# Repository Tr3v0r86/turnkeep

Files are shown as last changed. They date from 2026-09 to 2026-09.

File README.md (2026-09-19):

# Turnkeep

**Bring the game back to the table.** A printable case for dice, a miniature and a pen, with an offline character display powered by the non-touch LilyGo T-Display-S3.

Real dice, paper notes and an offline device for the pieces that matter. **Make it. Modify it. Copy it. Reinvent it. Make it yours.**

[Explore the website](https://tr3v0r86.github.io/turnkeep/) · [Hardware and assembly](hardware/) · [Firmware and character packs](firmware/)

## Build this prototype

The first public release combines the **v0.2 body and L-shaped rolling lid** with the **v0.3 adjustable screen module**. Keep the screen-module parts together. The bare shell is nominally 166 × 110 × 36 mm; final wrapped dimensions and mass have not been measured.

- `hardware/`: original editable CAD, printable exports, wrap patterns, BOM and assembly instructions.
- `firmware/`: standalone ESP-IDF project, host simulator and validated compile-time JSON character tooling. The included character is synthetic.
- `site/`: the complete static website, self-hosted fonts and images.
- `tools/`: deterministic release packaging and checksums, using Python's standard library.

Read the hardware guide before buying parts. Print fit checks first. Fit and finish depend on your printer, inserts and covering material. Choose and verify your own compatible battery and connector polarity.

## What works, what remains

The prototype interface supports two-button navigation, health edits, actions, spells, resources and offline state. Initial sleep and wake checks passed on the prototype. Personal JSON packs validate and compile into firmware; phone-based setup is not implemented.

[Try the phone-setup prototype](https://tr3v0r86.github.io/turnkeep/setup.html): scan a QR, preview Beyond/photo import, review a synthetic character and simulate a transfer. No actual OCR, Beyond integration or device pairing is implemented. CYD, colour e-paper and round-display [CAD concepts](hardware/concepts/) are unvalidated envelope studies, separate from the current printable design.

The v0.3 mechanical fit still needs physical acceptance. Battery runtime, standby current, thermal behavior, repeated recovery cycles and a complete tabletop session are not yet validated. This is an experimental maker release, not a finished consumer product. No ready-to-flash binary is advertised.

## Build the website and download package

```sh
python3 tools/release.py
python3 -m http.server 8197 --directory site
```

Open http://localhost:8197. `RELEASE_FILES.txt` is the explicit publication allowlist. The generated ZIP and manifest go into `site/downloads/`; the manifest records sizes, SHA-256 hashes and the source revision. GitHub Pages runs the same script. See [deployment](docs/deployment.md).

## License and contributions

Original hardware: CERN-OHL-P-2.0. Original firmware and website: MIT. Original docs and images: CC BY 4.0. [Full licensing map](LICENSE.md).

Issues and pull requests are welcome. Include the component revision, board version, printer/material or toolchain, exact reproduction steps and photographs or logs where helpful. Do not upload game-book extracts, other people's character art, device dumps, secrets or unlicensed models. Public releases of Turnkeep are maintained here; unrelated prototype projects are not automatically synchronized.

The files, firmware and guides stay free forever. Fully assembled boxes from Trevor are coming soon. [Buy Trevor a coffee](https://buymeacoffee.com/padlano) is optional support, not a preorder.

[Development roadmap](docs/roadmap.md): character import → CYD → phone companion → made-to-order builds → colour e-paper → round display.

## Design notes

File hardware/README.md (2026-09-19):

# Turnkeep hardware

A compact 166 × 110 × 36 mm bare case with a fixed screen corner and removable L-shaped lid. Flip the lid 180° and magnetically dock it to the front edge to make a rolling tray. Both halves rest on the table; the dock is not a carrying handle. Current geometry combines the retained v0.2 body/lid with the v0.3 faceplate and adjustable board support. This remains a prototype pending physical acceptance.

## Print and assemble

Print one each of `stl/01_body.stl` and `stl/02_rolling_lid.stl`, then `REPAIR_PRINT_PLATE.stl` once (eight electronics-module parts). Alternatively print the four module STL designs in the quantities encoded in their filenames. Units: millimetres, 100% scale. Body/lid: 0.4 mm nozzle, 0.20 mm layers, four walls, five top/bottom layers and 15–20% infill as an unverified starting profile. Inspect support preview around the horizontal docking holes. Module: 0.16 mm layers, four walls, 25% infill, no supports. Parts fit a 180 mm build envelope.

Print `08_fit_coupon` first to test insert/magnet fit, `09`/`10` to test lid clearance and `11`/`12` to test docking. Coupon rows at y=12/33/52 test 2.9–3.2 mm insert pilots, 6.1–6.4 mm large magnet pockets and 3.1–3.4 mm small magnet pockets, increasing left to right. Final pilot/pocket diameters are 3.0/6.3/3.3 mm. Test a module button/support before a full print; do not force tight fits.

Follow [the module assembly guide](ASSEMBLY.md), including first-contact-only support adjustment. Never use the screws to flatten a rocking board. Fit hardware and verify button return, display seating, reset and USB access before applying coverings. The front frame supports the display; the glass is not a clamp surface.

| Full-build item | Quantity / specification |
|---|---|
| Board | 1 LILYGO T-Display-S3, bare headers; verify your revision |
| Battery envelope | Up to 57 × 39 × 8 mm; compatible protected cell, connector/polarity verified against your board |
| Heat-set inserts | 12 M2, 4 mm long, 3.2 mm OD: four body, four faceplate, four adjusters |
| M2 × 8 mm screws | 8: four case screws, four adjusters |
| M2 × 10 mm screws | 4 carrier mounts |
| 6 × 2 mm magnets | 10: four closure, six docking |
| 3 × 2 mm magnets | 6 closure |
| Coverings | Nominal 2 mm felt floors; optional 1 mm PVC outside |
| Consumables | Suitable magnet/cover adhesive, thin soft battery mounting pad |

Dry-fit and mark all magnet polarities before gluing. Keep magnet faces, collars, sockets and lid mating edges clear of felt/PVC/glue. Route the battery wire clear of bosses and screw tips; its connector and bend path are not fully modelled. Do not clamp or puncture the cell. Seven dice pockets and a 155 × 16 mm pen pocket are nominal envelopes; test your contents. The small accessory pocket is generic and includes no miniature model.

## Source and reproduction

Use Python 3.14 (tested on macOS arm64). Create a virtual environment and install `requirements.txt`; `requirements-lock.txt` records the complete tested environment.

```sh
python -m venv .venv
. .venv/bin/activate
pip install -r requirements.txt
python build.py
python package.py
python upholstery/make_patterns.py
python upholstery/make_felt.py
python render.py
python verify.py
```

Run from `hardware/`. `case.py` defines the retained body/lid parametrically; `build.py` defines the current module and generates eleven printable designs (including five fit coupons), original-parts-only `case-assembly.step`, preview meshes and `validation.json`. STEP is editable boundary-representation geometry; Python is the parameter source. `package.py` produces the eight-piece print plate and a portable hardware map. `render.py` renders the actual case meshes to `../media/hero.png` without external fonts or private assets. No historical source mutation scripts are required. VTK rendering needs a graphics-capable session; on headless Linux provide a compatible EGL/OSMesa or Xvfb setup.

For nominal board/contact checks, acquire the manufacturer's model independently and run `python build.py --board-step /path/to/t-display-s3-full.stp`. It is never added to exported STEP or preview meshes. The default build explicitly records board checks as skipped; see [provenance](PROVENANCE.md).

## Coverings and verification

`upholstery/felt-pocket-templates.svg` and `make_felt.py` supply editable floor and lid felt templates with magnet/docking trim guides; verify the 100 mm line.

[Two-piece upholstery](upholstery/README.md) provides the editable generator and two actual-size A4 landscape PDF pages. Paper-test first, then test a scrap of the actual 1 mm material. Keep the current screen surround painted and removable. The shape check establishes exactly two connected nets; it does not prove physical PVC fit.

Build assertions check connected valid solids, watertight meshes, dimensions, non-overlap, insertion/adjustment sweeps, screw/battery clearances and open/closed lid geometry. Optional board checks cover clearances and contact areas. Physical printer tolerances, actual board revision, magnetic holding force, button loads, cable fit, upholstery and long-term creep remain unverified. This package does not claim a completed physical fit or slice validation.

AliExpress specification-search links for every material and common tools are in the [website materials list](https://tr3v0r86.github.io/turnkeep/#materials). Listings are not qualified suppliers; verify the variant and dimensions before buying.

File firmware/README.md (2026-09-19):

# Turnkeep firmware

A dedicated character companion for the **non-touch LilyGo T-Display-S3** (ESP32-S3, 16 MB flash, 8 MB octal PSRAM, 170×320 ST7789 panel used in 320×170 landscape). Other T-Display variants are not supported by this pin map. The portable character reducer and UI use the included TrevOS app contract; only the display and button support is board-specific.

## Build and install

Install [ESP-IDF v5.4](https://docs.espressif.com/projects/esp-idf/en/v5.4/esp32s3/get-started/index.html) with ESP32-S3 tools and activate its `export.sh`. Commands below run from `firmware/`. The first build downloads pinned public components, so it needs internet access. `dependencies.lock` records their resolved versions.

```sh
idf.py -C boards/tdisplay-s3 -B build-character build
# Only when ready to replace the firmware on your connected board:
idf.py -C boards/tdisplay-s3 -B build-character -p YOUR_SERIAL_PORT flash monitor
```

This is the sole build profile; no `CHARACTER_CASE` switch is needed. No credentials, Wi-Fi setup or cloud service are required. Back up any firmware/data you want to retain before flashing your own device; this repository contains no device backups. The partition table allocates a 3 MiB factory application and NVS for saved character counters.

## Controls and scope

KEY advances; holding KEY moves back. BOOT selects/confirms; holding BOOT returns. Holding both buttons and releasing the chord saves state and enters deep sleep; either button wakes the board. The case orientation is fixed in `main/main_character.c`. HP, temporary HP, spell slots and one named resource persist in NVS. Damage consumes temporary HP first; undo restores the previous in-memory transaction. Reference lists show actions, spells, checks and sheet notes.

The included Mara Vale fixture is synthetic demonstration data, not a rules compendium or an official character sheet. Content import is **compile-time JSON → generated C header → rebuild/flash**. Runtime JSON loading, phone import, Bluetooth upload, an encounter tracker and multi-character selection are not implemented. There is one spell-slot pool and one class-resource pool; short rest rules and class mechanics are not automated. Pack text accepts printable ASCII and the middle dot only, matching the supplied font repertoire. Control characters and broader Unicode text are rejected. Battery percentage/current, endurance and thermal performance have not been measured for this public build. The simulator uses volatile in-memory NVS and cannot prove physical sleep, battery behavior or retention across process restarts.

## Edit content and verify

Python 3 uses only the standard library. `schemas/character/character-pack-v1.schema.json` documents the bounded format; `dev.py` is the executable validator. Change the character ID when replacing a character to start fresh counters; the ID hashes to the saved-state generation key. Editing content while keeping the same ID preserves compatible saved counters.

```sh
python3 tools/character/dev.py doctor
python3 tools/character/dev.py validate fixtures/character/synthetic-mara-vale.json
python3 tools/character/dev.py generate fixtures/character/synthetic-mara-vale.json apps/character/include/character_pack_generated.h
python3 -m unittest tools/character/tests/test_pack.py
cc -std=c11 -Wall -Wextra -Werror -Iapps/character/core/include apps/character/core/test_character_core.c apps/character/core/character_core.c -o /tmp/turnkeep-core
/tmp/turnkeep-core
cc -std=c11 -Wall -Wextra -Werror -Iboards/tdisplay-s3/main boards/tdisplay-s3/test/test_button_filter.c boards/tdisplay-s3/main/button_filter.c -o /tmp/turnkeep-buttons
/tmp/turnkeep-buttons
```

The tracked generated header is intentional: firmware builds need no Python pack-generation step, and the drift test checks it matches the fixture. Keep only content you have permission to redistribute in public packs.

## Desktop simulator and source

Requires CMake, a C compiler, POSIX threads and SDL2 development files. Build the device once to populate managed LVGL sources, or supply `-DLVGL_DIR=/path/to/lvgl-9.6.0`. Install SDL2 through your package manager; if CMake cannot discover it, supply `-DCMAKE_PREFIX_PATH=/path/to/sdl2` (on Apple Silicon Homebrew, `/opt/homebrew/opt/sdl2`).

```sh
cmake -S sim -B sim/build
cmake --build sim/build --target charactersim -j
./sim/build/charactersim
# Headless smoke run and native-size PPM screenshot:
SIM_DISP=null SIM_TICKS=120 SIM_SHOT=/tmp/turnkeep.ppm ./sim/build/charactersim
```

Type `KEY`, `KEY_LONG`, `BOOT`, `BOOT_LONG`, `CHORD`, or `QUIT` on stdin. UI, character core, shell and board entry point are the device sources; display, buttons and storage are host seams. SDL2 is still a build dependency for headless runs. [THIRD_PARTY.md](THIRD_PARTY.md) covers dependencies, font source and licenses; [PROVENANCE.md](PROVENANCE.md) records the extraction boundary.

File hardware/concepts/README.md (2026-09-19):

# Future display envelope studies

These three original CAD mockups explore larger Turnkeep cases. They are visual concepts, **not printable release parts, compatible replacements, or verified electronics enclosures**. Use the current hardware directory for the actual prototype.

| Study | Assumed outer envelope | Assumed display bay | Visual screen panel |
|---|---|---|---|
| CYD | 198 x 132 x 42 mm | 94 x 64 mm | 72 x 48 mm |
| Colour e-paper | 224 x 150 x 40 mm | 112 x 82 mm | 90 x 62 mm |
| Round screen | 190 x 142 x 40 mm | 82 x 82 mm | 62 mm diameter |

All dimensions above are chosen design envelopes. The CYD study is inspired by a larger touchscreen; its panel is not a claim about any particular CYD active area or PCB. The colour e-paper and round-screen modules are deliberately unspecified. All three need a selected board/module, official drawings, measured mounting/connector/battery dimensions and a complete mechanical redesign before printing. No electronics, holes, switch access, screw mounts, magnets, wiring routes or working docking interface have been engineered into these studies. Their lid-open poses illustrate the intended arrangement only.

## Files and regeneration

Run `python concepts/build.py` then `python concepts/render.py` from `hardware/`, with the parent directory's pinned requirements installed. Rendering requires a graphics-capable session (VTK). All geometry is original; no vendor CAD or miniature asset is embedded.

Each study has an editable `concept.step` assembly with four solids plus five view STL meshes (`body`, `deck`, `screen_placeholder`, `lid`, `lid-open`). STL files remain in assembly coordinates; they are visual envelopes, not print-oriented components. `build.py` is the editable parameter source. `validation.json` records shape validity/watertightness; those checks do not establish fit or function.

The render script creates `media/cyd-concept.png` and `media/epaper-concept.png` and `media/round-concept.png` with explicit concept labels. The colour e-paper image uses original coloured patches and text-line shapes as illustrative screen content, not working UI; these render-only marks are not part of the enclosure CAD. The round concept uses a thin circular placeholder, with no selected display or board. It also renders `media/closed.png` and `media/exploded.png` from the unchanged current prototype meshes in `hardware/preview_meshes/`; those two images show actual current geometry with electronics omitted. Exploded offsets are visual separation only.

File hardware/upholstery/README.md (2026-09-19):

# Two connected upholstery nets

Exactly two connected material pieces: lid outside top with connected side flaps, and base underside with connected side flaps. The screen surround remains painted.

## Print and fit

Print `output/pdf/Turnkeep-TWO-PIECE-wrap-nets-A4.pdf` on A4 landscape at 100% actual size. One complete net fits on each page; no tiling or joining. Verify each 100 mm line. Solid outlines are cuts; blue dashed lines are gentle folds, never cuts or scores. Grey dotted lines locate the corner wings, which remain attached. The base net is mirrored to show the underside from outside; its USB opening appears on the right.

Cut and tape the paper first. Keep the printed face outward when trial-fitting. Put that printed face DOWN when tracing onto the PVC backing. Test the bend with a scrap of actual 1 mm PVC before cutting the final material. Glue the broad face first, fold the flaps around the edges, then curve the attached wings around the vertical corners. Butt and trim the joins; do not force overlaps. Small compound-corner reliefs and the screen surround remain painted. No material turns into the case or covers the inner L-notch walls.

## Geometry and limitations

Derived from the retained v0.2 body/lid (166 x 110 mm; base lower wall 20 mm; lid 16 mm; fixed screen corner 31.6 mm). The current v0.3 deck remains exposed and removable. R5 corner wings use the neutral radius of nominal 1 mm material (5.5 mm). Flaps include a provisional 0.5 mm bend/trim allowance with 0.3 mm seam setback; this is a trial pattern, not a measured material-specific bend model. Body upper corner flaps stop at the original straight-wall transitions. Docking collars, sockets, finger recess and USB have clearance cutouts.

Shapely verifies each finished cut outline is one valid connected polygon after all reliefs and openings; exactly two material pieces. The PDF is two actual-size A4 landscape pages, rendered and visually inspected. Physical PVC fit and glue behavior remain unverified. Do not infer tested upholstery fit from the geometry checks.

## Reproduction

Run `python make_patterns.py` with Shapely, ReportLab and pypdf installed. Outputs live under `output/pdf/`; `validation.json` records dimensions and connectivity.

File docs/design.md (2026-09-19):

# Turnkeep website design

## Identity

Turnkeep keeps the pieces and state of a tabletop turn together. The descriptor is **An open-source character case**; the lead is **A character case, open by design**. This is a maker project, with honest evidence and direct access to its files. The case geometry is the central visual, not invented fantasy ornament. The name is a working project name, not a claim of trademark clearance.

## Visual system

| Token | Hex | Role |
| --- | --- | --- |
| Felt | #183B46 | Main background |
| Deep seam | #102A33 | Footer and recesses |
| Ivory | #F0F1E8 | Light surfaces and text |
| Brass | #E2B96F | Primary action |
| Ink | #17323B | Text on light surfaces |
| Muted | #B7CDD0 | Secondary text on dark |

Bricolage Grotesque carries the wordmark, headings and body; IBM Plex Mono carries dimensions and technical labels. Fonts are locally hosted with OFL notices. Body text is 18 px with 1.55 line height. The asymmetric desktop opening becomes a single column on narrow screens. The L-shaped tray and compartment geometry should remain recognizable in all replacement hero imagery. Label CAD renders as renders; do not present them as physical build evidence.

## Reader path

The case → how it works → build guidance → files → development journal. A single static document keeps navigation and downloads available without JavaScript. Technical detail lives beside its editable source in the repository. Full-project download includes the original sources and exports; per-file SHA-256 checksums expose exactly what is inside.

## Accessibility and maintenance

Use semantic sections, a first-focus skip link, visible keyboard focus, native disclosures and visible navigation. Keep illustrations paired with text descriptions. Preserve 320 px reflow and readable tables. Respect reduced-motion preference. Do not add autoplay or scroll hijacking. Update evidence labels when a physical check actually passes, and version the file set when geometry or firmware changes.

The product thesis now leads: **Bring the game back to the table.** Phone preparation supports offline play instead of competing with it. The setup demo is an interactive, explicitly simulated flow; the real current device and future display concepts remain visibly distinct. The maker invitation is **Make it. Modify it. Copy it. Reinvent it. Make it yours.** Keep optional coffee support separate from the upcoming assembled-box offer.

On 2026-09-19 Trevor explicitly required the actual CAD model and actual firmware UI in the hero. Product views now use deterministic model rendering; AI-generated product geometry is not used. The site art direction is a tabletop drafting mat: restrained brass registration/route marks, stronger editorial typography, material lighting and user-controlled open/packed/exploded views. Styling surrounds the model instead of inventing product features.

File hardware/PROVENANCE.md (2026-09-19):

# Hardware provenance

The case design and generators were authored for the project. This public package extracts the current geometry from the original `trevos-enclosure-repair-v0.3` and retained `trevos-character-case-v0.2` designs. `case.py` contains only the retained body/lid portion of `reference/source_v02.py`; `build.py` is the v0.3 generator adapted to import it normally and make manufacturer-board checks optional. No miniature model, personal character sheet, derived miniature image, historical repair, backup or entire archive folder is included.

`package.py` retains the original eight-piece layout and hardware-map drawing with portable fonts. `upholstery/make_patterns.py` retains the current two-connected-net geometry; the product title changes to Turnkeep. `render.py` is a new portable render of the generated original-part STL meshes, not an illustrative replacement design. The current faceplate stays bare/painted. No model of the electronic board appears in the public render.

The external manufacturer reference is [LILYGO T-Display-S3 board STEP](https://github.com/Xinyuan-LilyGO/T-Display-S3/blob/main/dimensions/t-display-s3-full.stp), SHA256 `d33dc105aa1e25a1408f3effda5a59319ef69044984d57ccb6d482bb78a589a5`. Its redistribution license has not been established, so the reference, its derived meshes, and assemblies embedding it are excluded. The optional `--board-step` argument uses a separately acquired file only for checks; exported STEP always contains original printed parts only. Dimensional interfaces in the original design were fitted against that reference; current physical hardware remains the acceptance authority.

`validation.json` is produced by the default source build and states whether board checks ran. `validation-with-board.json`, when present, is a result-only record from the separately acquired nominal model. It contains measurements/check outcomes and no model geometry. Dependency licenses remain their respective authors'; Python packages are installed rather than vendored.

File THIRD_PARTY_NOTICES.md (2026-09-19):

# Third-party notices

- Optional QR asset generator: `qrcode` 8.2, BSD-3-Clause, installed separately. The generated QR encodes only the public setup-demo URL.
- Website Bricolage Grotesque: SIL Open Font License 1.1; [license](LICENSES/Bricolage-OFL.txt), [source](https://github.com/google/fonts/tree/main/ofl/bricolagegrotesque).
- Website IBM Plex Mono: SIL Open Font License 1.1; [license](LICENSES/IBM-Plex-OFL.txt), [source](https://github.com/google/fonts/tree/main/ofl/ibmplexmono).
- Firmware component dependencies and bundled font derivatives retain the notices in `firmware/` and the dependency packages. ESP-IDF, LVGL and Espressif components are fetched by the documented toolchain, not relicensed by this project.
- CAD generation uses CadQuery and its dependencies; rendering uses the dependencies listed in the hardware guide. Those packages retain their upstream licenses and are installed separately.
- The LilyGo T-Display-S3 is third-party hardware. Manufacturer CAD is not redistributed. The original reference is available from [LilyGo's dimensions directory](https://github.com/Xinyuan-LilyGO/T-Display-S3/tree/main/dimensions). Any optional local use must follow the upstream terms.

Original renders exclude third-party miniature meshes and manufacturer board geometry. The screen capture uses a synthetic example character. Turnkeep is an independent maker project, with no claim of endorsement by game publishers or board manufacturers.

The product hero uses original CAD meshes and the actual synthetic-character firmware screenshot. Material colors and lighting are illustrative; product geometry is rendered deterministically.

The kit layout is a deterministic render of original case meshes and the real synthetic-character UI. Purchased components are original geometric illustrations, not manufacturer CAD or a finalized packing list. Felt and leather are shown as material blanks. Source: `hardware/render_kit.py`.

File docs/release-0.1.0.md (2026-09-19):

# First experimental release

## Matched components

Version `0.1.0-prototype.2`: retained v0.2 body and lid, v0.3 adjustable screen module, two-piece wrap nets and standalone character firmware. Use the complete module: one faceplate, one carrier, two buttons and four insulating supports. The repair plate contains those eight pieces. Full-build instructions and fastener quantities are in `hardware/README.md`.

Website update: the hero now renders the unchanged original CAD meshes and the actual 320×170 firmware UI. Open/packed/exploded controls, original vector tabletop artwork and revised typography/style are included. `hardware/render_product.py` reproduces the images; the media validation record hashes all inputs. The domain guide now explains root GitHub Pages hosting with an inherited `/turnkeep/` path, rather than an address-changing redirect.

## Evidence

CAD default build passed 114 geometric checks. A separate nominal manufacturer-board reference run passed 163 checks; that reference is excluded from the distribution. Saved deliverables verified as 10 valid original STEP solids, 11 watertight STL designs with matching hashes, an eight-piece repair plate and a two-page A4 landscape wrap PDF.

ESP-IDF 5.4 clean build passed: application size 666,768 bytes, 79% partition free. Nine CharacterPack test methods and strict C11 character/button tests passed. The desktop simulator built and rendered the included synthetic character. No physical device was flashed during public extraction.

Website checks: local fonts/images loaded, no overflow at 320, 390, 768 and 1440 pixels, valid in-page anchors, first-focus skip link and working native assembly disclosure. Actual-geometry hero and module images were visually inspected on desktop/mobile. Full assistive-technology testing is not claimed.

The website adds a working browser-only phone-setup demonstration: local photo preview, link-format validation, synthetic field review, validated CharacterPack download, simulated device transfer and after-game counter export. Browser flow checks passed at 320 and 390 pixels. Node boundary checks passed. Three future-display CAD studies (CYD, colour e-paper, round) regenerate into 12 valid solids and 15 watertight concept meshes. The ordered roadmap and AliExpress specification-search links are published.

## Known limits

Physical v0.3 fit acceptance, upholstery trial, battery runtime/current, thermal behavior and repeated recovery tests remain open. No battery model/capacity or final cost is asserted. Character loading requires rebuilding firmware; there is no phone uploader. The public character is synthetic. No ready-to-flash image is distributed.

## Provenance and reuse

The public repository starts with fresh history and original sources only. Manufacturer CAD, third-party miniatures and derived imagery are excluded. Runtime/toolchain dependencies are acquired from their upstream sources. The source ZIP contains only `RELEASE_FILES.txt` entries; `manifest.json` identifies the exact source commit, byte sizes and SHA-256 checksums. The GitHub prerelease assets are the versioned snapshot; later main-branch website builds do not replace those assets.

## Build options

Custom assembled boxes and build-it-yourself kits from Trevor are shown as coming soon alongside the free self-sourced build. An example parts layout uses unchanged original CAD and the actual UI, with clearly identified illustrative components and material blanks. Final kit contents and battery selection remain unvalidated.

## Mobile layout

Compact phone navigation, reduced heading scale, concise copy and native disclosures for technical details. Desktop content stays expanded. Hash navigation reveals nested details; phone setup uses the direct link instead of a QR image.

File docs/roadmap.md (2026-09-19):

# Turnkeep development roadmap

An evolving storage system for nerds, for when your hobby is building things for your hobbies.

## Starting point

A real T-Display-S3 prototype and open CAD exist today. Character JSON can be validated and compiled into firmware. The website phone flow is an interactive demonstration; Beyond import, photo recognition and wireless device transfer are not implemented. The current v0.3 mechanical fit, power behavior and recovery still need physical acceptance. The sequence below is intentional; dates come after each milestone is scoped and validated.

## Development sequence

| Order | Work | First useful delivery | Acceptance before moving on |
| --- | --- | --- | --- |
| 1 | Character import | A reviewed CharacterPack from a supported character source, with an explicit path to the current device. Start with the validated JSON format, then a supported D&D Beyond export/link route and sheet-photo extraction. | Missing/uncertain fields are visible; user approves the pack; identity and counter replacement are deliberate; invalid input cannot destroy the working character. Verify real source access before promising direct service integration. |
| 2 | CYD edition | A larger color-display version using a selected CYD board, with a new enclosure, controls and shared character format. | Measure the exact PCB/panel, validate power and controls, print and physically fit the enclosure, run a full offline session. The current concept CAD is only an envelope study. |
| 3 | Phone companion | Boot-and-scan pairing, review/import, transfer to the case, after-game export and level-up replacement. Start with a mobile web companion; evaluate a native app only where device transport requires it. | Real pairing and transfer work on named phone/browser combinations; interrupted sync preserves the last good pack; conflicts are explained; play remains offline. OCR and service connections clearly expose errors and uncertain fields. |
| 4 | Made-to-order builds | Fully assembled, tested boxes from Trevor with a clear bill of materials, price, lead time and supported firmware. | Physical-fit/power/recovery checks pass, packing and repair guidance exist, a repeatable bench acceptance checklist is used, and order terms are published before payment is taken. Coffee support is not a preorder. |
| 5 | Colour e-paper edition | A selected colour e-paper panel and a low-distraction character view in a revised case. | Measure refresh latency, readability, ghosting and power; choose which fields refresh together; verify controls, enclosure and a tabletop session. No battery-life promise from the mockup. |
| 6 | Round-display edition | A compact round-screen take on the same offline companion and modular storage idea. | Design a genuinely readable circular interface; verify display/controller selection, controls, power and physical fit; retain the shared import format where practical. |

## What stays constant

Real dice, paper and people stay central. Phone use belongs before and after play. Working files, firmware and build guides stay free forever. Versions must distinguish tested parts from visual concepts and current features from demonstrations. The website updates as the project evolves; new ideas do not silently become supported hardware.

**Make it. Modify it. Copy it. Reinvent it. Make it yours.**

Made-to-order offering also includes a build-it-yourself kit. Publish a validated packing list, battery specification, tools/adhesives required, assembly instructions and pricing before accepting kit orders. Custom assembled builds and kits remain coming soon; free sources are available now.

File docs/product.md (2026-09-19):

# Bring the game back to the table

## Thesis

Keep tabletop games tactile and social: real dice, paper notes, a miniature and the people around the table. Turnkeep adds a small offline companion for health, resources and reference details. The phone handles preparation; it goes away when play starts.

**Make it. Modify it. Copy it. Reinvent it. Make it yours.** Original files, firmware and guides stay free forever under their open licenses. The website follows the evolving design. Fully assembled boxes from Trevor are planned; optional coffee support does not buy or reserve a box.

## Intended session

Boot the box, scan its QR code, pair the phone and choose a character. Bring in a D&D Beyond character link or a photograph of a paper sheet, review the extracted fields, then transfer the character to Turnkeep. Play offline with physical dice and paper. After the session, review/export changed counters. When the character levels up, review an updated sheet and replace the device pack deliberately.

Review is essential: character import must identify missing/uncertain fields rather than invent rules or silently overwrite session state. Future sync must resolve character identity and counter conflicts explicitly. Uploading to Turnkeep and writing back to D&D Beyond are separate capabilities; the latter depends on supported service access and is not promised.

## Current prototype boundary

Current firmware uses validated compile-time CharacterPack JSON. `site/setup.html` demonstrates the intended phone journey using synthetic data. A pasted Beyond URL is format-checked but never fetched. A selected photo is previewed locally but never uploaded or recognized; sample extraction remains explicitly synthetic. The review can download a valid CharacterPack JSON; device pairing/transfer and after-game sync are simulations. Nothing is saved to a server.

The QR in this website opens the public demo. It is not a pairing credential. Real pairing, transport, authentication, firmware upload handling, image recognition, approved character-source access and conflict handling remain implementation work. Choose and validate the device transport before promising a phone/browser compatibility matrix.

## Hardware direction

Current build: T-Display-S3 case with v0.2 body/lid and v0.3 module. Future studies: larger CYD color display a colour e-paper display and a round-screen edition. `hardware/concepts/` contains shared parametric envelope studies, not fit-tested printable parts. Panel selection, controls, refresh behavior, power and mechanical compatibility must be verified before either becomes a build release.

The broader direction is an evolving storage system for nerds: for when your hobby is building things for your hobbies. The [roadmap](roadmap.md) records the ordered milestones.

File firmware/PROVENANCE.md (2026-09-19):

# Firmware provenance

Extracted from the author’s `esp-devwork` commit `f3aa75b8f6ce97cb6ea94e7bc5e375f03e8ac9ba` as a new standalone source tree, without importing its Git history.

Included: `apps/character` (portable reducer, UI, tests); the two-button T-Display-S3 character entry point, display and input support; the TrevOS app contract, shell, shared UI and required font sources; a character-only exact-source desktop simulator; CharacterPack schema, standard-library Python generator/validator and tests; synthetic Mara Vale fixture and a newly regenerated header.

Excluded: all personal character fixtures and their generated header/review; all unrelated boards and applications; Todoist, Wi-Fi credentials and sync integrations; device identifiers, private notes, firmware backups, old screenshots and build products; touch/round simulator targets; screenshot streaming service; LED-strip dependencies. Downloaded managed components and local build/configuration output are ignored.

Standalone adaptations: only the Character app is registered; CMake lists only needed components; managed GUI dependencies are pinned; SDL2 is discovered through CMake rather than a machine-specific prefix; required null values and text outside the font repertoire are rejected; personal-fixture tests are removed and the generated-header drift test targets Mara Vale. Device flashing was not performed during extraction.

## Extraction verification (2026-09-19)

On macOS: Python standard-library pack suite, 9 tests passed; C11 character reducer and button-filter tests passed with `-Wall -Wextra -Werror`. ESP-IDF 5.4 built the dedicated target from fresh sdkconfig defaults using esp_lvgl_port 2.9.0 and LVGL 9.6.0~1. The app image is 666,768 bytes with 79% of its 3 MiB partition free. SDL2 simulator compiled, rendered the synthetic Mara overview at native 320×170, and completed KEY/BOOT/Back/sleep-chord input with no deadlock. Physical flashing, current draw and endurance are not verification claims for this extracted build.

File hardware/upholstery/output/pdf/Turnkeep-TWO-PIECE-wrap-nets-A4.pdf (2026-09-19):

# 1 - LID: outside top + attached sides

ONE connected PVC piece on this page. Solid = CUT. Blue dashed = FOLD gently; do not cut or score.

Grey dotted = corner-wing guide. The corner wings stay attached. No separate strips. No inward turn-ins.

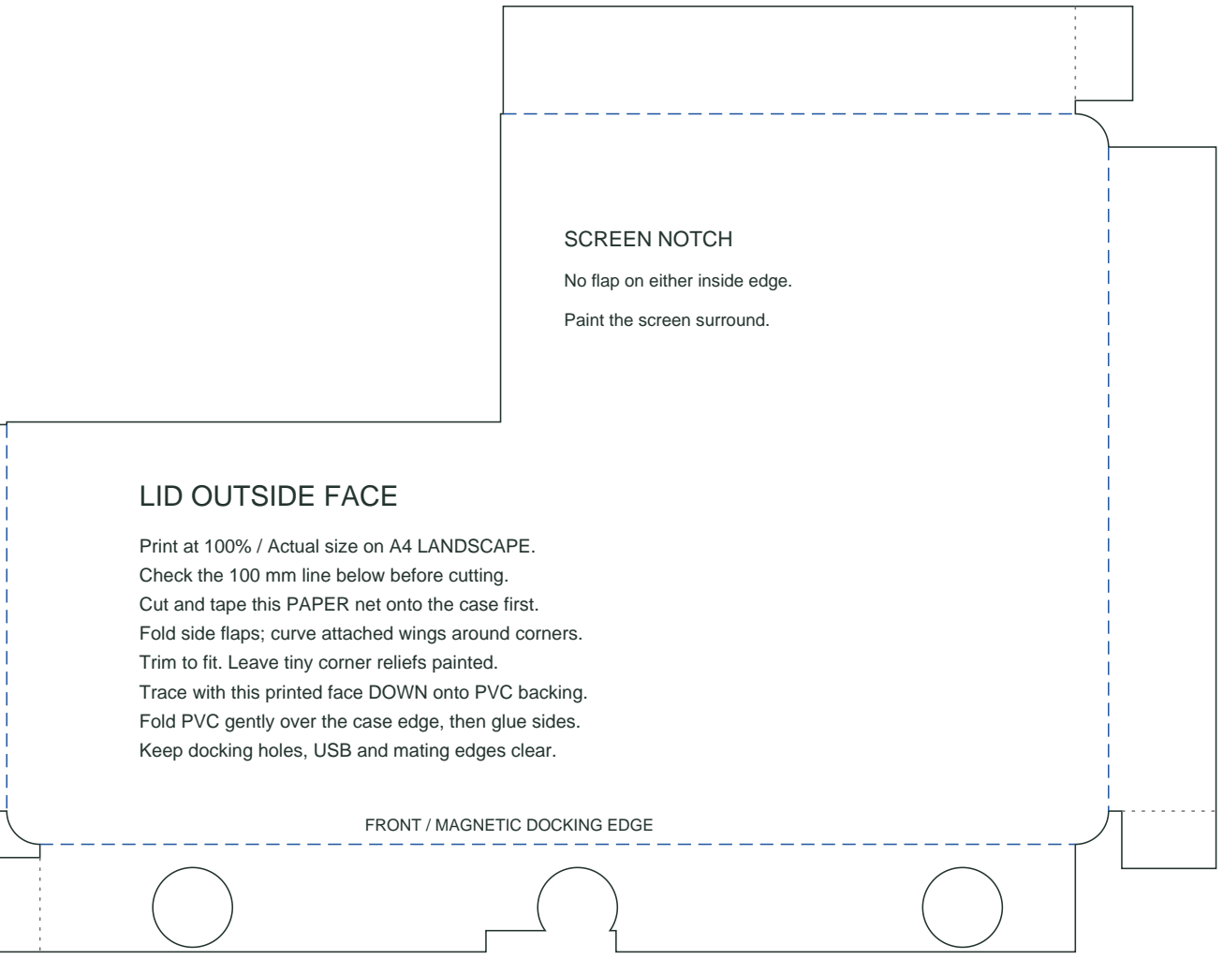
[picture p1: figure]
LID OUTSIDE FACE; SCREEN NOTCH; No flap on either inside edge.; Paint the screen surround.; FRONT / MAGNETIC DOCKING EDGE

Print at 100% / Actual size on A4 LANDSCAPE. Check the 100 mm line below before cutting.
Cut and tape this PAPER net onto the case first. Fold side flaps; curve attached wings around corners. Trim to fit. Leave tiny corner reliefs painted.
Trace with this printed face DOWN onto PVC backing. Fold PVC gently over the case edge, then glue sides. Keep docking holes, USB and mating edges clear.
100% / NO FIT TO PAGE | 1 mm PVC | Paper + scrap trial required

100 mm

# 2 - BASE: underside + attached sides

ONE connected PVC piece on this page. Solid = CUT. Blue dashed = FOLD gently; do not cut or score.

Grey dotted = corner-wing guide. The corner wings stay attached. No separate strips. No inward turn-ins.

## BASE UNDERSIDE

Print at 100% / Actual size on A4 LANDSCAPE. Check the 100 mm line below before cutting.
Cut and tape this PAPER net onto the case first. Fold side flaps; curve attached wings around corners. Trim to fit. Leave tiny corner reliefs painted.
Trace with this printed face DOWN onto PVC backing. Fold PVC gently over the case edge, then glue sides. Keep docking holes, USB and mating edges clear.

OUTSIDE VIEW - USB cutout on RIGHT

Taller flaps cover the fixed screen-corner walls.

FRONT / MAGNETIC DOCKING EDGE

100% / NO FIT TO PAGE | 1 mm PVC | Paper + scrap trial required

100 mm

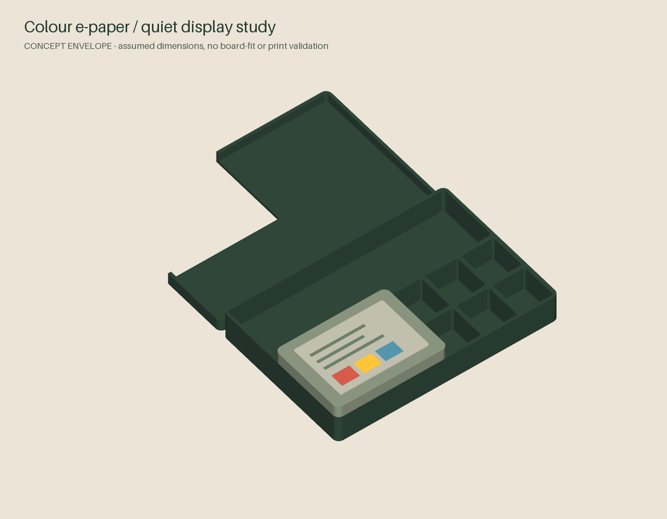
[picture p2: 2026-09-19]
media/epaper-concept.png

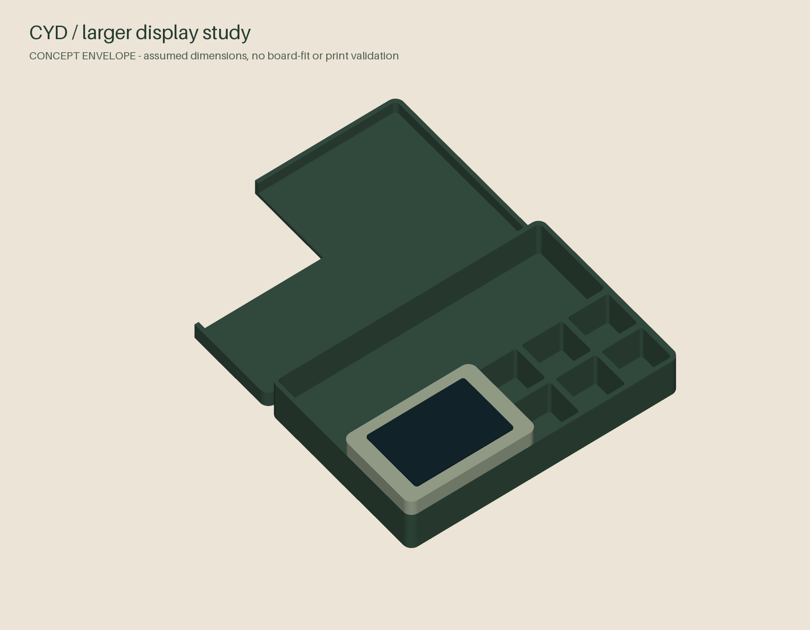
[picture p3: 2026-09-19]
site/assets/cyd-concept.png

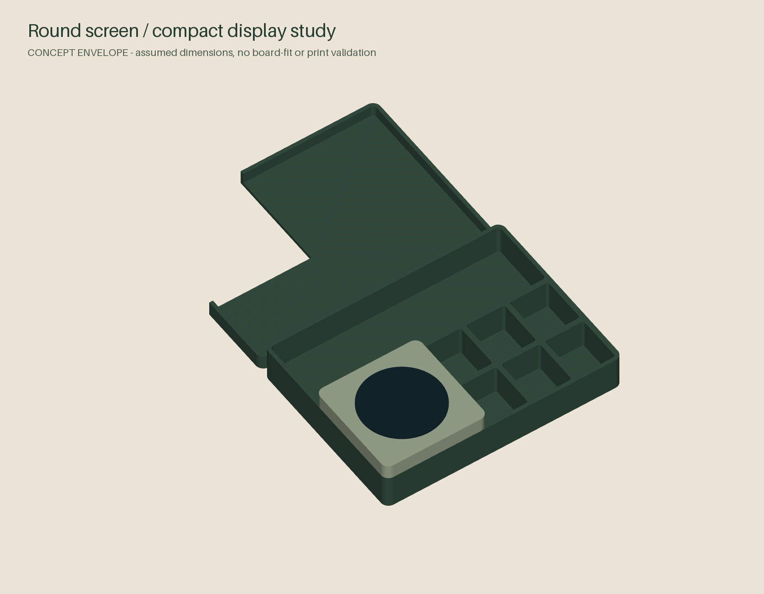
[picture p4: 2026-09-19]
site/assets/round-concept.png

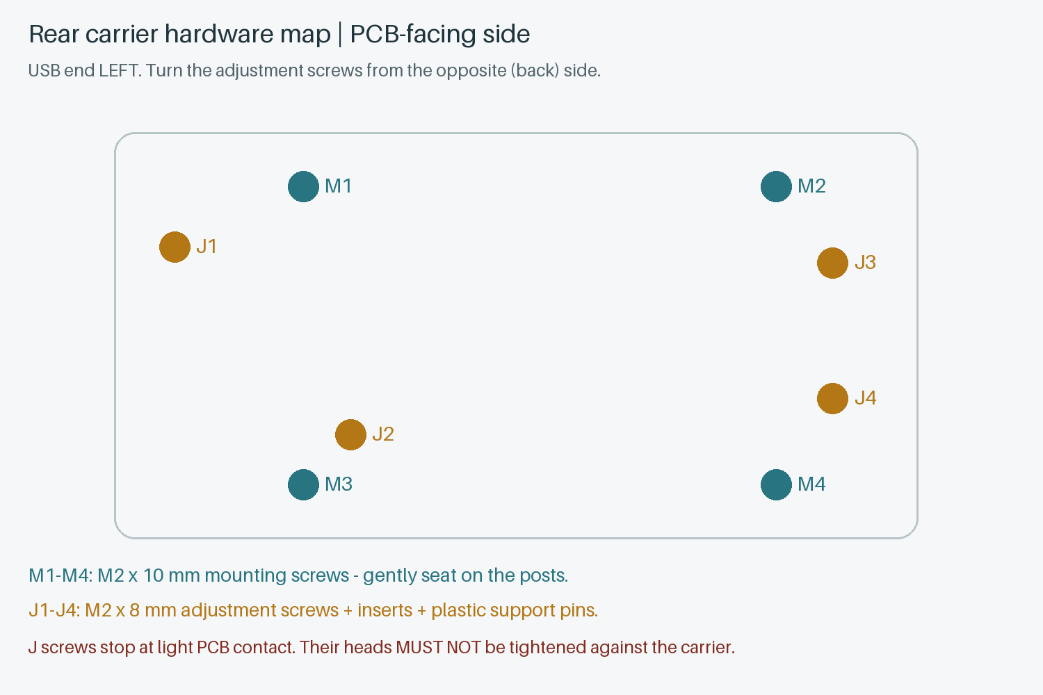
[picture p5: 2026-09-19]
hardware/hardware-map.png

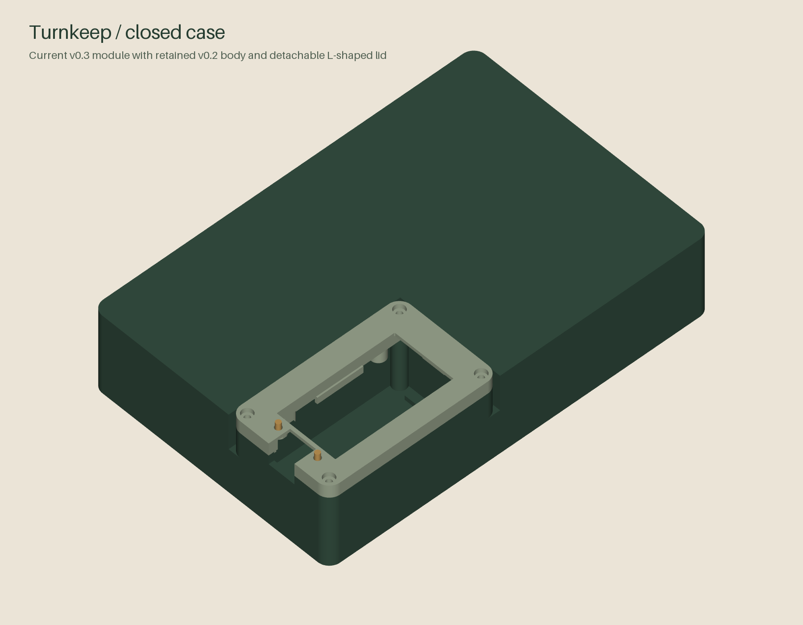
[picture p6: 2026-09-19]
media/closed.png

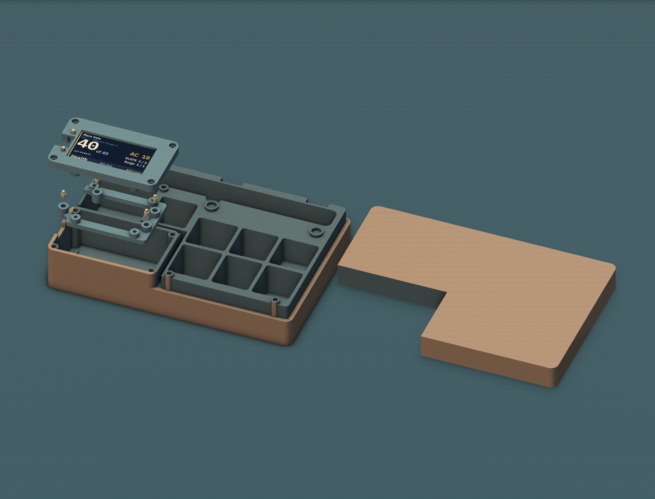
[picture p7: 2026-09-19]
media/product-exploded.png

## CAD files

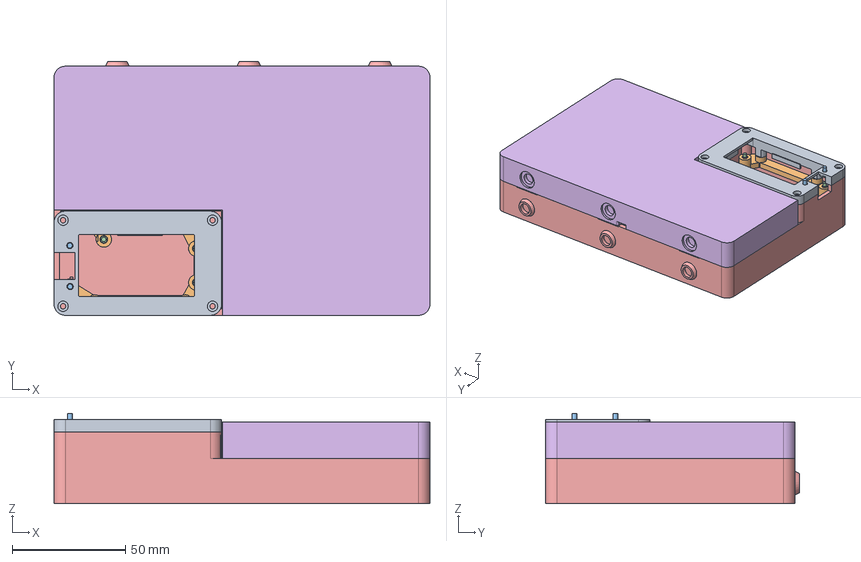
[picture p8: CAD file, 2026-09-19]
hardware/case-assembly.step
166.0 x 112.0 x 39.8 mm
deck
retainer
button_0
button_1
existing_body
existing_lid

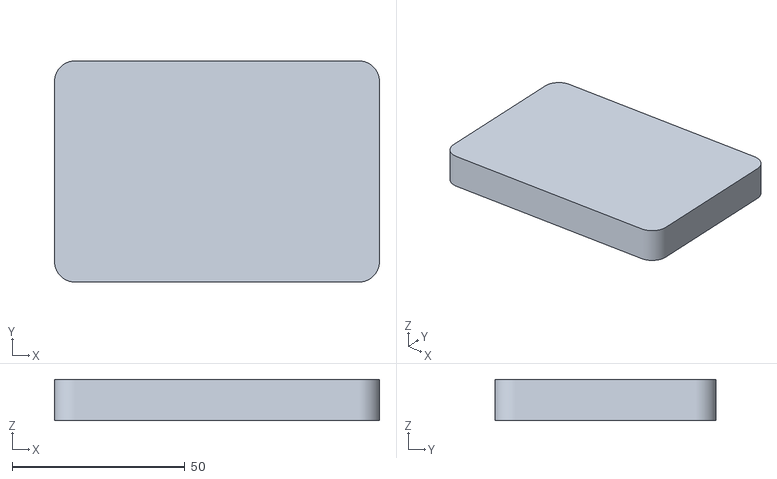
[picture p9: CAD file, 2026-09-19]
hardware/concepts/cyd/deck.stl
94.0 x 64.0 x 12.0

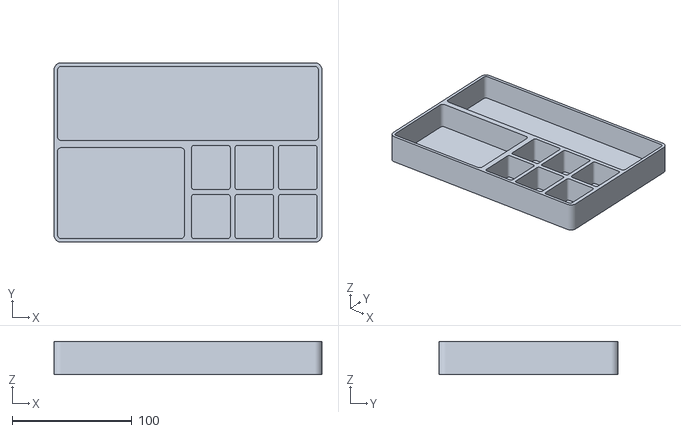
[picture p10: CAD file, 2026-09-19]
hardware/concepts/epaper/body.stl
224.0 x 150.0 x 28.0

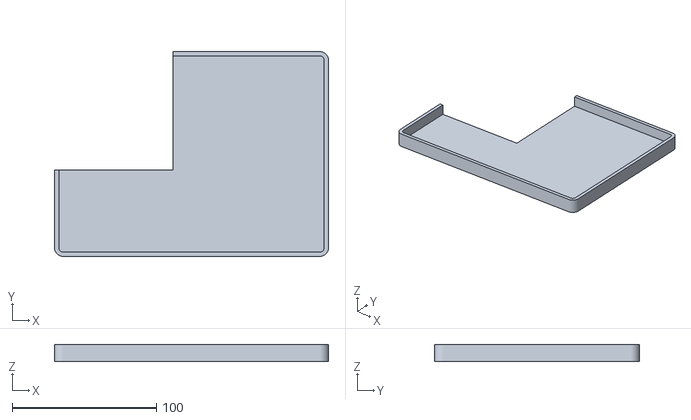
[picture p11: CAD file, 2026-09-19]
hardware/concepts/round/lid-open.stl
190.0 x 142.0 x 12.0

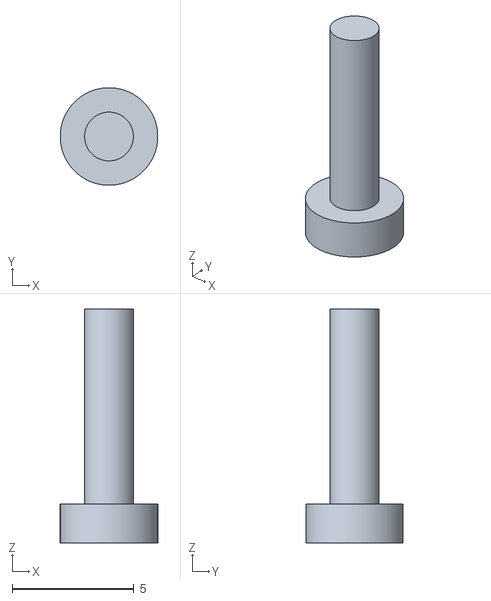
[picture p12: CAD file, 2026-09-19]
hardware/preview_meshes/jack_2.stl
4.00 x 4.00 x 9.60

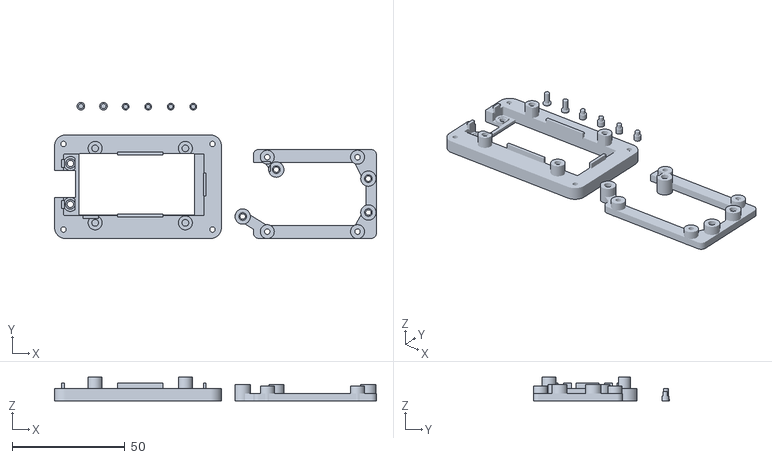
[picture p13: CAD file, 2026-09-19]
hardware/REPAIR_PRINT_PLATE.stl
142.7 x 60.4 x 10.6

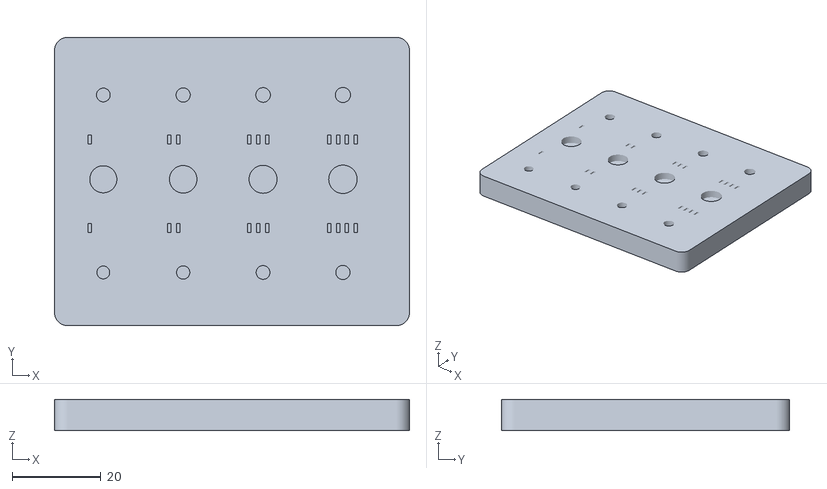
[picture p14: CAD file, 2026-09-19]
hardware/stl/08_fit_coupon.stl
80.0 x 65.0 x 7.00

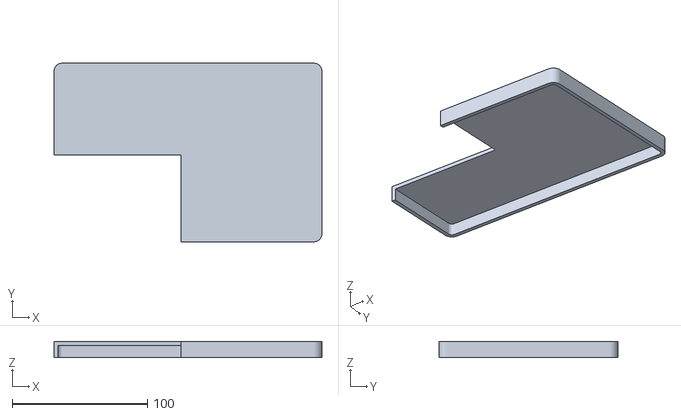
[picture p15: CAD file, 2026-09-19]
hardware/concepts/cyd/lid.stl
198.0 x 132.0 x 12.0

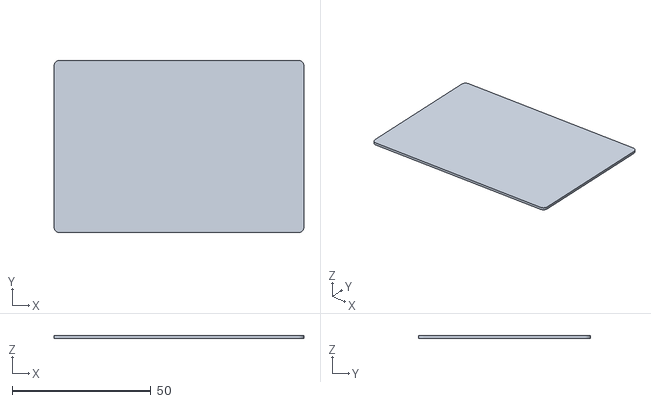
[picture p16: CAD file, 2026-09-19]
hardware/concepts/epaper/screen_placeholder.stl
90.0 x 62.0 x 1.00

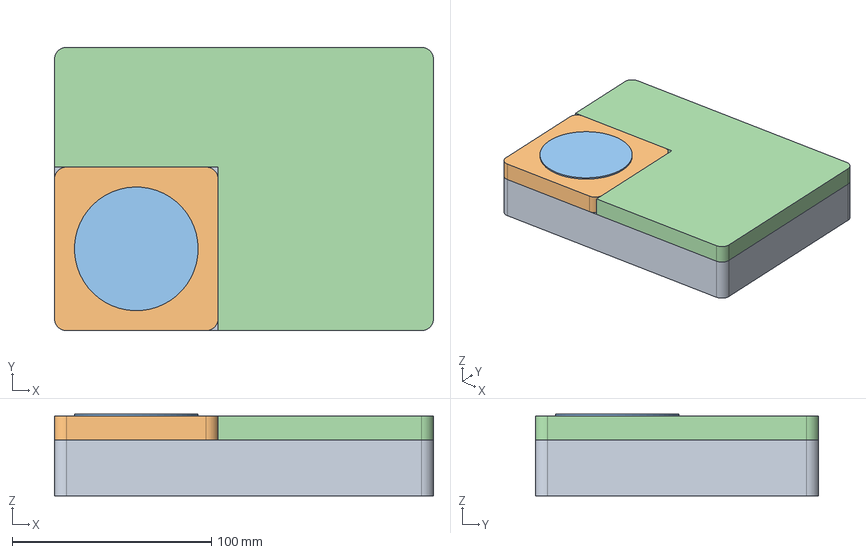
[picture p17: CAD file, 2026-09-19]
hardware/concepts/round/concept.step
190.0 x 142.0 x 41.0 mm
deck
screen_placeholder
lid

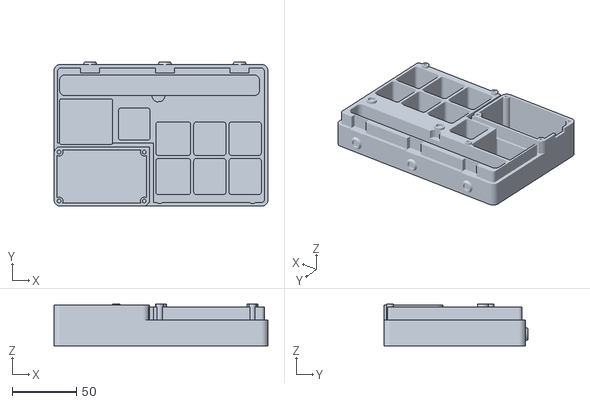
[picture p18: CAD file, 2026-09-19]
hardware/preview_meshes/body.stl
166.0 x 112.0 x 32.2

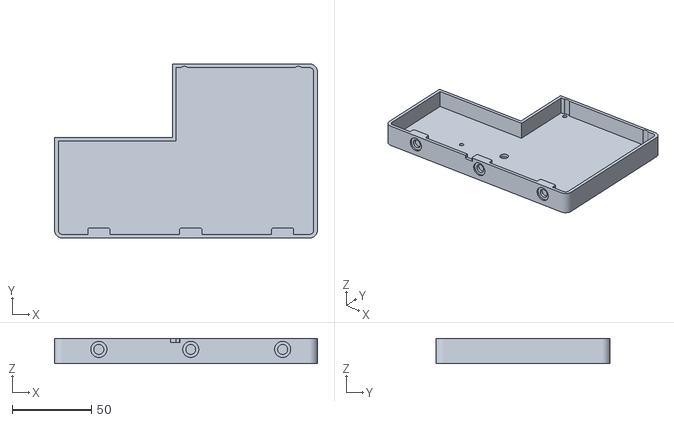
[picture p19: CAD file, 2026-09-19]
hardware/stl/02_rolling_lid.stl
166.0 x 110.0 x 16.0

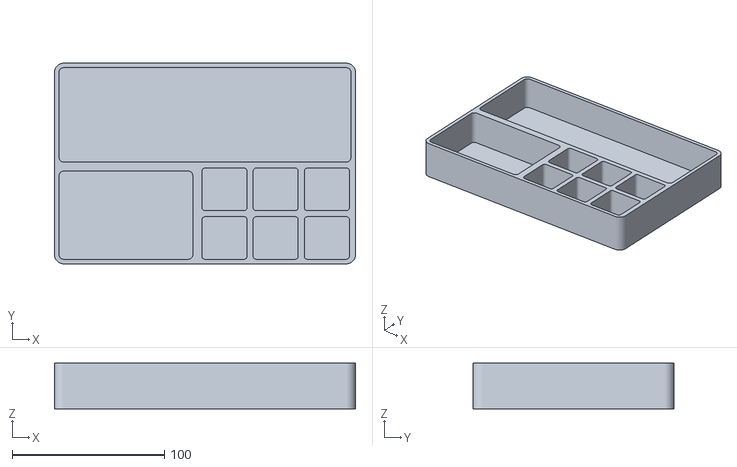
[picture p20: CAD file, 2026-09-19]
hardware/concepts/cyd/body.stl
198.0 x 132.0 x 30.0

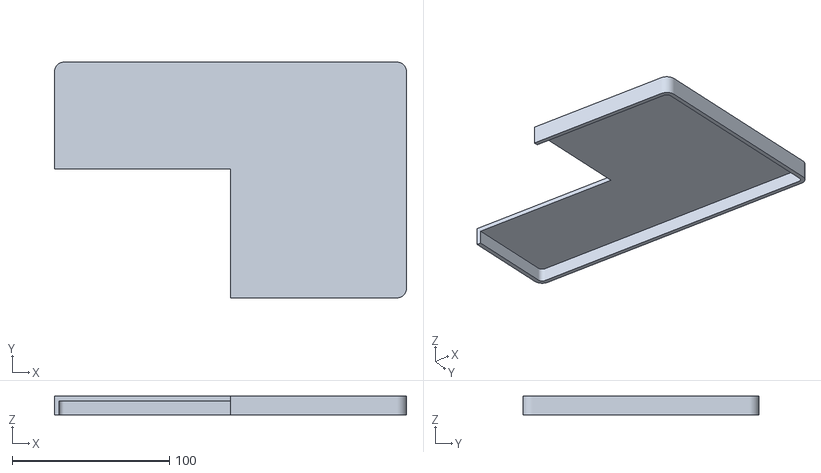
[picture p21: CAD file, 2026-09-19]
hardware/concepts/epaper/lid.stl
224.0 x 150.0 x 12.0

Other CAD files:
hardware/concepts/round/lid.stl
hardware/preview_meshes/pad_3.stl
hardware/stl/01_body.stl
hardware/concepts/cyd/lid-open.stl
hardware/concepts/cyd/concept.step
hardware/concepts/cyd/screen_placeholder.stl
hardware/concepts/epaper/concept.step
hardware/concepts/epaper/deck.stl
hardware/concepts/epaper/lid-open.stl
hardware/concepts/round/body.stl
hardware/concepts/round/deck.stl
hardware/concepts/round/screen_placeholder.stl
hardware/preview_meshes/button_0.stl
hardware/preview_meshes/button_1.stl
hardware/preview_meshes/deck.stl
hardware/preview_meshes/jack_0.stl
hardware/preview_meshes/jack_1.stl
hardware/preview_meshes/jack_3.stl
hardware/preview_meshes/lid.stl
hardware/preview_meshes/open_docked_lid.stl
hardware/preview_meshes/pad_0.stl
hardware/preview_meshes/pad_1.stl
hardware/preview_meshes/pad_2.stl
hardware/preview_meshes/retainer.stl
hardware/stl/03_faceplate_v03.stl
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

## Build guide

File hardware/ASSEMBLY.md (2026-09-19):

# Turnkeep v0.3 — matched screen-enclosure repair

Replace the complete screen module's printed parts together. Reuse the case
body, magnetic rolling lid, board and battery. Do not mix in old plungers,
the old retainer or the separate old bezel. This is a CAD-checked fit revision;
the board still needs the physical seating and adjustment checks below.

## 1. What to print

**Easiest: print `REPAIR_PRINT_PLATE.stl` once.** It contains all eight pieces,
already oriented and spaced for the A1 Mini. Import at 100% in millimetres;
keep all pieces on the bed. It is intentionally eight disconnected objects.
Alternatively, use the individual files in `stl/`:

| Part | Copies |
|---|---:|
| 03_faceplate_v03 | 1 |
| 04_adjustable_retainer_v03 | 1 |
| 05_front_button_PRINT_2 | 2 |
| 06_insulating_support_PRINT_4 | 4 |

Use PLA or PLA Matte, 0.4 mm nozzle, **0.16 mm layers**, four walls and 25%
infill, normal speed, no supports. Small buttons/support tips should resolve
as solid in the slicer. Avoid draft layers for this repair. The faceplate is
front-face down; the carrier is flat-back down; both types of pin have their
wide base down. Deburr first-layer edges and keep all sliding surfaces clean.

The module's flat front is now 1.2 mm higher, occupying the old bezel's height.
The separate bezel is eliminated. The glass remains recessed, not perfectly
flush. Keep this module unwrapped until it passes the functional fit test.
Old leather patterns for the faceplate need adapting to the new opening and
button positions. Body/lid patterns are unaffected.

`stl/` contains the unchanged retained body and rolling-lid
STLs if a complete reprint is wanted. They are not needed for this repair.

## 2. Hardware and hole identification

The brass "hot melt nuts" in your kit are heat-set inserts. Use the **M2,
4 mm long, 3.2 mm outside-diameter** size for the eight new insert locations.
Install them straight and flush, with the electronics and plastic pins absent.

| Use | Hardware |
|---|---|
| Four inner faceplate mounting posts | 4 M2 heat-set inserts, 4 mm long |
| Four rear carrier adjustment bosses | 4 M2 heat-set inserts, 4 mm long |
| Carrier to faceplate, positions M1–M4 | 4 M2 x 10 mm screws |
| Rear support adjustment, J1–J4 | 4 M2 x 8 mm screws |
| Faceplate to existing case | Reuse 4 M2 x 8 mm screws and existing case inserts |

See `hardware-map.png`. The carrier's mounting holes are plain clearance
holes. Only its four J holes get brass inserts, installed from the flat BACK.
The plastic support pins enter the wider guide bores from the PCB-facing side.

**M screws seat normally. J screws do NOT seat against the carrier:** their
heads intentionally stand away from its back. Tightening a J screw all the
way could bend the board. Each J screw pushes an insulating plastic tip;
no metal screw should touch the PCB.

## 3. Assembly and physical acceptance check

1. Fit-test the empty faceplate first. Remove the old bezel, all old plungers
   and the old carrier. Rest the new faceplate front-down on a soft clean cloth.
   Lower the board vertically into it. The display FRAME should sit level on
   both short-end shoulders. The glass, native buttons, USB connector and reset
   switch must not jam. There are no edge-gripping grooves and no snap-in step.
   If it rocks or needs force, stop here; do not use screws to flatten it.
2. Lift out the board and insert the two new FRONT buttons from inside,
   narrow end first. The wide feet stay inside. Check they slide freely and
   their stems emerge through the front. Refit the board; it must still sit
   level. Do not proceed if the button end rises.
3. Before attaching the carrier, install its four support pins, wide body
   into each guide and narrow tip toward the PCB. They are loose until captured.
   A small strip of thin removable tape across each tip can hold it in place
   during assembly; keep it flat if it remains over the tip. Do not use felt
   or foam as the support. Start the J screws from the back only far enough
   to engage the inserts, leaving all pins fully retracted. Confirm each pin
   can slide in its guide before assembly; do not force a tight printed pin.
4. Lower the carrier straight onto the four faceplate posts, with its USB-end
   arm matching the board's USB end. Fit M1–M4 using M2 x 10 screws and tighten
   gently to the mounting shoulders. The board may have play at this stage;
   the carrier must not bow and its pins must not lift the board.
5. Keep the frame seated in the faceplate. Advance J1–J4 a little at a time,
   stopping each at FIRST light contact with the PCB. Use the diagram to see
   their contact locations. Tips must meet bare PCB, not a chip, connector or
   reset switch. Do not add a tightening turn after contact. The four settings
   may differ. This takes up actual assembly height, including any thin tape.
6. Turn the module over. Both front buttons must click and release independently
   without moving the PCB or flexing either printed plate. Check screen seating
   and reset clearance again. Test powered operation before fitting the module
   to the case. If a press moves the board, inspect the corresponding support;
   if the frame starts lifting or bowing, back the adjustment off.
7. Route the battery lead through the open centre, clear of the adjustment
   screws. Fit the module using the existing case screws. Recheck both buttons,
   reset access and USB cable access with the module installed. Repeat the
   check after the first session of use; PLA creep and loose screws were not
   evaluated by the CAD checks.

## 4. What was checked, and what remains physical

The downloadable package includes `validation.json`, the parts-only STEP
assembly, source and previews. With the optional external board model, automated checks cover valid connected solids,
watertight exported meshes, A1 Mini print bounds, nominal board/component
clearance, bare-PCB contact area under every support tip, front FRAME seating,
button insertion and plastic travel envelopes, pin adjustment, screw envelopes,
board approach, small XY positioning offsets, battery clearance, existing body,
closed lid and docked rolling tray. Print orientation was visually reviewed.

The glass is not the intended clamp surface. The native-switch pockets now
have about 1.68 mm nominal height clearance outside the plunger foot, versus
0.08 mm in the old rectangular recess. The plunger stems and native switches
share centre lines. The carrier has no board-gripping rails.

These checks do **not** certify your printer's dimensional accuracy, exact
board revision, switch force/travel, structural load performance or a successful
physical fit. No FEA or physical button-load test has been performed. The
adjustable supports accommodate height variation but cannot compensate for a
board that fails steps 1–2. Do those checks before wrapping or final assembly.

Reference: LILYGO's public `T-Display-S3/dimensions/t-display-s3-full.stp`.
Its SHA256 is D33DC105AA1E25A1408F3EFFDA5A59319EF69044984D57CCB6D482BB78A589A5.
The board model is not redistributed here; its reuse license has not been established. This repair
changes how that geometry is located and supported; it does not claim a newer
or independently measured board model.

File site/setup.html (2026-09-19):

Skip to setup

Interactive design prototype · Imports and device transfers are simulated

TurnkeepBack to the build

A phone for setup. A case for play.

# Bring the game back to the table.

Prepare on your phone. Play on your case. Try the planned journey here, free and without an account. Everything stays in this browser tab.

TurnkeepDisplay preview

First boot concept

## Your next adventure starts here.

QR code to open this prototype on your phone Open phone setup (https://tr3v0r86.github.io/turnkeep/setup.html)

Scan with your phone camera

Mara Vale

Elf / Eldritch Knight 4

40of 40 HP

AC 18Slots 3 / 3Surge 1 / 1

Health KEY next · BOOT open

A live browser illustration of the proposed case experience. The current firmware does not display this setup QR or connect to a phone.

1. 1. Choose
2. 2. Review
3. 3. Play

Start with a source below. No sign-in needed.

## Start with your sheet.

Choose how you would bring in a character. For this prototype, both paths lead to synthetic sample data.

Character sourceD&D Beyond linkPreview the link-import journeyA photo of your sheetPreview the photo-import journey Character link

We only check the link’s format. This demo never visits D&D Beyond, reads a character or asks for credentials.

Check link & use sampleSkip the link. Try Mara Vale.

Choose a sheet image

JPEG, PNG or WebP, up to 10 MB. Previewed locally, never uploaded. There is no text recognition in this demo.

Use sample extraction

This loads Mara Vale’s synthetic data, not text from your image.

## Make it your character.

Synthetic example · Mara Vale

Check the essentials, then try the simulated transfer. Actions, spells and resource limits remain the sample’s values.

Character name1–40 printable ASCII characters or middle dots.

Maximum HP

Armor class

Level

Simulate sync to caseDownload character JSON

Choose a different source

The downloaded CharacterPack JSON works with the current validator and compile-time generator. It is not a wireless import.

## Ready for the next turn.

Simulation complete · No device was connected

The preview now holds your reviewed character. At the table, the intended experience is offline: your case keeps the counters while your phone stays away.

Try changing HP during the game

Update display preview

### When the dice are put away.

Try the proposed return trip: export the counters, or review a new level before replacing the character.

Simulate after-game syncReview a level-up

After-game sync downloads a demo session-state JSON file. It does not update D&D Beyond or any device. Level-up replacement resets the preview to full HP; no class features are recalculated.

Start a new setup

What works today: offline firmware, local counters and compiled JSON packs.
What this explores: QR onboarding, phone imports and two-way sync.

Inspect the open-source project

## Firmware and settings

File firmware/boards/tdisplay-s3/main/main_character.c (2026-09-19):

#include "bsp_buttons.h"
#include "bsp_display.h"
#include "character_app.h"
#include "trevos.h"
#include "esp_lvgl_port.h"
#include "esp_log.h"
#include "driver/gpio.h"
#include "nvs_flash.h"
#include "lvgl.h"

#ifndef CHARACTER_SIM
#include "driver/rtc_io.h"
#include "esp_sleep.h"
#endif

static const char *TAG = "character_case";
static esp_lcd_panel_handle_t s_panel;

static void sleep_now(void)
{
    if (!character_app_prepare_sleep()) {
        ESP_LOGE(TAG, "sleep refused: state not saved");
        return;
    }
#ifdef CHARACTER_SIM
    ESP_LOGI(TAG, "simulated sleep after stable chord release");
#else
    ESP_LOGI(TAG, "sleep entry levels: GPIO0=%d GPIO14=%d",
             gpio_get_level(GPIO_NUM_0), gpio_get_level(GPIO_NUM_14));
    bsp_display_power_off(s_panel);
    // EXT1 switches these pads to RTC IO; keep the active-low buttons inactive in sleep.
    ESP_ERROR_CHECK(rtc_gpio_pulldown_dis(GPIO_NUM_0));
    ESP_ERROR_CHECK(rtc_gpio_pullup_en(GPIO_NUM_0));
    ESP_ERROR_CHECK(rtc_gpio_pulldown_dis(GPIO_NUM_14));
    ESP_ERROR_CHECK(rtc_gpio_pullup_en(GPIO_NUM_14));
    ESP_ERROR_CHECK(esp_sleep_enable_ext1_wakeup_io(
        (1ULL << 0) | (1ULL << 14), ESP_EXT1_WAKEUP_ANY_LOW));
    ESP_LOGI(TAG, "deep sleep; GPIO0 or GPIO14 wakes");
    esp_deep_sleep_start();
#endif
}

static void on_btn(bsp_btn_t btn, bsp_btn_evt_t evt, void *ctx)
{
    (void)ctx;
    if (!lvgl_port_lock(0)) return;
    if (evt == BSP_BTN_SLEEP_CHORD) sleep_now();
    else if (btn == BSP_BTN_KEY && evt == BSP_BTN_PRESS) trev_input_turn(TREV_TURN_NEXT);
    else if (btn == BSP_BTN_KEY && evt == BSP_BTN_LONG) trev_input_turn(TREV_TURN_PREV);
    else if (btn == BSP_BTN_BOOT && evt == BSP_BTN_PRESS) trev_input_commit();
    else if (btn == BSP_BTN_BOOT && evt == BSP_BTN_LONG) trev_input_back();
    lvgl_port_unlock();
}

void app_main(void)
{
    ESP_ERROR_CHECK(nvs_flash_init());

#ifndef CHARACTER_SIM
    esp_sleep_wakeup_cause_t wake = esp_sleep_get_wakeup_cause();
    if (wake == ESP_SLEEP_WAKEUP_EXT1) {
        ESP_LOGW(TAG, "woke by EXT1 mask=0x%llx",
                 (unsigned long long)esp_sleep_get_ext1_wakeup_status());
    } else {
        ESP_LOGI(TAG, "wake cause=%d", wake);
    }
#endif

    esp_lcd_panel_io_handle_t io;
    ESP_ERROR_CHECK(bsp_display_init(&io, &s_panel));
    const lvgl_port_cfg_t port_cfg = ESP_LVGL_PORT_INIT_CONFIG();
    ESP_ERROR_CHECK(lvgl_port_init(&port_cfg));

    const lvgl_port_display_cfg_t display_cfg = {
        .io_handle = io,
        .panel_handle = s_panel,
        .buffer_size = BSP_LCD_H_RES * 40,
        .double_buffer = true,
        .hres = BSP_LCD_H_RES,
        .vres = BSP_LCD_V_RES,
        .monochrome = false,
        // Character Case is installed opposite the legacy T3 orientation.
        .rotation = { .swap_xy = true, .mirror_x = true, .mirror_y = false },
        .flags = { .buff_dma = true, .swap_bytes = false },
    };
    lv_display_t *display = lvgl_port_add_disp(&display_cfg);
    (void)display;

    if (lvgl_port_lock(0)) {
        trev_init(lv_screen_active());
        trev_app_register(&CHARACTER_APP);
        trev_set_home_app(0);
        trev_open(0);
        lvgl_port_unlock();
    }

    bsp_display_backlight_on();
    bsp_buttons_init(on_btn, NULL);
    ESP_LOGI(TAG, "Character Case MVP up: 320x170 landscape, case rotation");
}

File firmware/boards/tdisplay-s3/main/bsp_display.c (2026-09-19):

// bsp_display.c — LilyGo T-Display-S3 display BSP: ST7789, 170x320, 8-bit i80.
//
// Pins are reference from the LilyGo schematic. First light (2026-06-20) confirmed
// the panel powers up via GPIO15 and renders R/G/B/W correctly with swap_color_bytes
// + colour inversion + a 35px column gap, so the colour path below is settled.
#include "bsp_display.h"
#include "driver/gpio.h"
#include "esp_check.h"
#include "esp_lcd_panel_vendor.h"
#include "esp_log.h"
#include "freertos/FreeRTOS.h"
#include "freertos/task.h"

#define PIN_POWER_ON 15   // LCD power enable -> HIGH or the screen stays dark
#define PIN_BL       38   // backlight
#define PIN_RD        9   // 8080 RD -> tie HIGH
#define PIN_WR        8   // i80 pixel clock
#define PIN_DC        7
#define PIN_CS        6
#define PIN_RST       5
#define PIN_D0       39
#define PIN_D1       40
#define PIN_D2       41
#define PIN_D3       42
#define PIN_D4       45
#define PIN_D5       46
#define PIN_D6       47
#define PIN_D7       48
// GAP under landscape (swap_xy/MADCTL MV on): esp_lcd_panel_st7789 adds x_gap to
// CASET and y_gap to RASET in draw_bitmap BEFORE the MV transpose happens in the
// controller. With MV on, CASET bounds the 320 extent (needs gap 0) and RASET bounds
// the 240-wide GRAM column axis where the panel sits at cols 35..204 (needs gap 35).
// So the 35px offset lives on Y in landscape, NOT X. (35,0) overflows CASET to 354 =>
// garbage band; (0,35) addresses [0,319]x[35,204] cleanly. Panel offset is symmetric
// 35/35 so mirror cannot reintroduce it. See esp_lcd_panel_st7789.c draw_bitmap.
#define X_GAP         0
#define Y_GAP        35

static const char *TAG = "bsp_disp";

void bsp_display_backlight_on(void) { gpio_set_level(PIN_BL, 1); }

void bsp_display_power_off(esp_lcd_panel_handle_t panel)
{
    gpio_set_level(PIN_BL, 0);
    if (panel) esp_lcd_panel_disp_on_off(panel, false);
    gpio_set_level(PIN_POWER_ON, 0);
}

esp_err_t bsp_display_init(esp_lcd_panel_io_handle_t *ret_io, esp_lcd_panel_handle_t *ret_panel)
{
    gpio_config_t gc = {
        .pin_bit_mask = (1ULL << PIN_POWER_ON) | (1ULL << PIN_RD) | (1ULL << PIN_BL),
        .mode = GPIO_MODE_OUTPUT,
    };
    gpio_config(&gc);
    gpio_set_level(PIN_POWER_ON, 1);
    gpio_set_level(PIN_RD, 1);
    gpio_set_level(PIN_BL, 0);                 // off until the first frame
    vTaskDelay(pdMS_TO_TICKS(20));

    esp_lcd_i80_bus_handle_t bus = NULL;
    esp_lcd_i80_bus_config_t bus_cfg = {
        .dc_gpio_num = PIN_DC,
        .wr_gpio_num = PIN_WR,
        .clk_src = LCD_CLK_SRC_DEFAULT,
        .data_gpio_nums = { PIN_D0, PIN_D1, PIN_D2, PIN_D3, PIN_D4, PIN_D5, PIN_D6, PIN_D7 },
        .bus_width = 8,
        .max_transfer_bytes = BSP_LCD_H_RES * 80 * 2,
    };
    ESP_RETURN_ON_ERROR(esp_lcd_new_i80_bus(&bus_cfg, &bus), TAG, "i80 bus");

    esp_lcd_panel_io_handle_t io = NULL;
    esp_lcd_panel_io_i80_config_t io_cfg = {
        .cs_gpio_num = PIN_CS,
        .pclk_hz = 6 * 1000 * 1000,
        .trans_queue_depth = 10,
        .dc_levels = { .dc_idle_level = 0, .dc_cmd_level = 0, .dc_dummy_level = 0, .dc_data_level = 1 },
        .lcd_cmd_bits = 8,
        .lcd_param_bits = 8,
        .flags = { .swap_color_bytes = 1 },    // high-byte-first RGB565 to the ST7789
    };
    ESP_RETURN_ON_ERROR(esp_lcd_new_panel_io_i80(bus, &io_cfg, &io), TAG, "panel io");

    esp_lcd_panel_handle_t panel = NULL;
    esp_lcd_panel_dev_config_t panel_cfg = {
        .reset_gpio_num = PIN_RST,
        .rgb_ele_order = LCD_RGB_ELEMENT_ORDER_RGB,
        .bits_per_pixel = 16,
    };
    ESP_RETURN_ON_ERROR(esp_lcd_new_panel_st7789(io, &panel_cfg, &panel), TAG, "st7789");
    ESP_ERROR_CHECK(esp_lcd_panel_reset(panel));
    ESP_ERROR_CHECK(esp_lcd_panel_init(panel));
    ESP_ERROR_CHECK(esp_lcd_panel_invert_color(panel, true));
    // Rotation (swap_xy/mirror) is owned by esp_lvgl_port, NOT here. lvgl_port_add_disp
    // re-applies swap_xy+mirror from disp_cfg.rotation at rotation-0 init, clobbering
    // anything set on the panel before it. Setting them here is dead code + the source
    // of the upright-portrait + garbage-band bug. See main.c disp_cfg.rotation.
    // Gap is NOT touched by lvgl_port, so it stays set here: (35,0) in BOTH orientations
    // because esp_lcd swaps x/y before adding the gap.
    ESP_ERROR_CHECK(esp_lcd_panel_set_gap(panel, X_GAP, Y_GAP));
    ESP_ERROR_CHECK(esp_lcd_panel_disp_on_off(panel, true));

    *ret_io = io;
    *ret_panel = panel;
    ESP_LOGI(TAG, "ST7789 %dx%d i80 up", BSP_LCD_H_RES, BSP_LCD_V_RES);
    return ESP_OK;
}

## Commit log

2026-09-19 feat: publish Turnkeep open-source prototype
    [01_body.stl, 02_rolling_lid.stl, 03_faceplate_v03.stl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]
2026-09-19 feat: add tabletop thesis, phone demo and development roadmap
    [body.stl, concept.step, deck.stl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]
2026-09-19 feat: add CAD-guided hero and Porkbun domain guide
2026-09-19 feat: render actual CAD and UI with richer website art direction
